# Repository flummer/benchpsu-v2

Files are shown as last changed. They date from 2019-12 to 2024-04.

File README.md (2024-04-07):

# Benchtop PSU v2

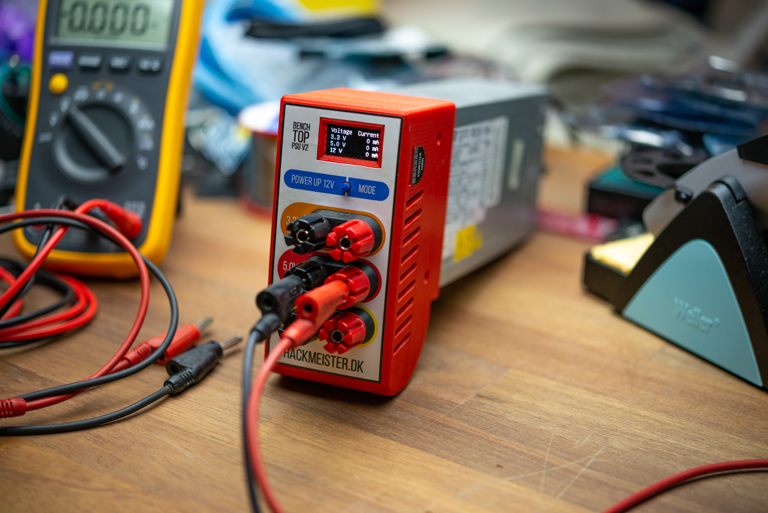
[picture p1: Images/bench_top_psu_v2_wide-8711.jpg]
Benchtop PSU v2


This is a conversion of an HP DPS-800GB server power supply, into a benchtop supply with connectors more commonly used for electronics and electrical prototyping.

It's designed to be relatively easy to make, and not least easier to assemble, as there are no dangling wires to solder, and the front part can be assembled by itself and then mounted on the PSU. The only modification I have done to the PSU is to remove the retaining clip, simply by opening the case and drilling out the rivet, holding it in place. It's not a critical modification, but I prefered to get rid of it.

## Features

This is a fairly simple conversion, and there are 3 fixed outputs:

- 3.3 V (5 A max)
- 5.0 V (2 A max)
- 12 V (30 A max)

The DPS-800GB PSU can deliver **much** more than 30A on 12 V, but the measuring circuit used for that channel has a max rating of 30A and the traces on the PCB probably also have a limit, though they have been made as wide as posssible to cope with a bit more current.

The screen will display the current draw on each output.

As the 3.3 V and 5.0 V outputs are part of the standby system in the DPS-800GB, they are always on, but the 12 V output is controlled via an optocoupler from the microcontroller, and the firmware is set up so that the single button turns that on and off.

## Notes

When mains power is connected, the fan is **not** running, but the PSU will get a bit warm if it sits like that for some time and it will also draw about 15W just sitting there, which isn't ideal. When the 12 V output is enabled, the fan will kick in, but unless you put a heavy load on it, it will only run slowly and not be super noisy, though it isn't silent in any way.

## Electronics

The electronics is build around an ATmega328p microcontroller and 3 ACS712 current sensors with analog output, and the firmware has some magic numbers for converting the value read from the analog inputs into ampere. Those have been found by putting a few known loads on the PSU and looking at the readings. It's a bit hacky, but good enough for a quick measurement if you just need to know if you are in the ballpark.

The banana connectors are the Pomona 6883 Dual Binding post and they are also used to hold the PCB inside the 3D printed case, and the friction of the connector and the 3D print against the case of the DPS-800GB is enough to keep it together, though the 3D model do have holes that match up with the existing screws of the DPS-800GB.

The card edge connector used to match with the DPS-800GB is an Amphenol FCI 10046971-001LF.

## License

The hardware, firmware, 3D models and artwork in this repository are released under the following license:

* the "Creative Commons Attribution-ShareAlike 4.0 International License"
  (CC BY-SA 4.0) full text of this license is included in the LICENSE file
  and a copy can also be found at
  [http://creativecommons.org/licenses/by-sa/4.0/](http://creativecommons.org/licenses/by-sa/4.0/)

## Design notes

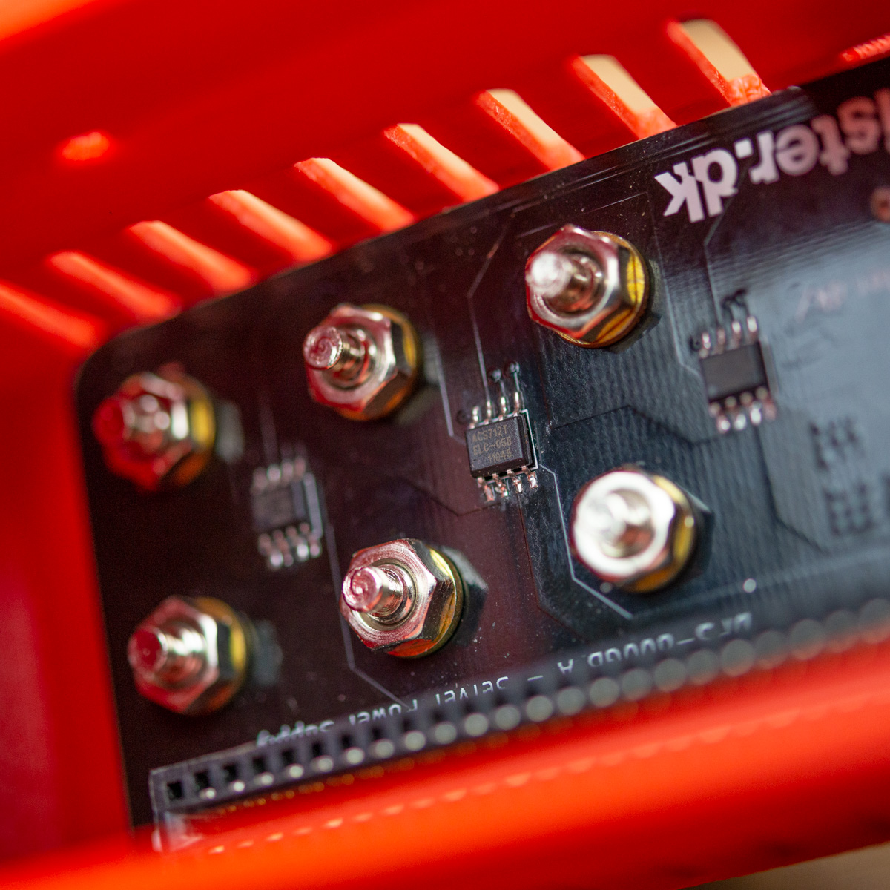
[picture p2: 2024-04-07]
Images/bench_top_psu_v2-8725.jpg

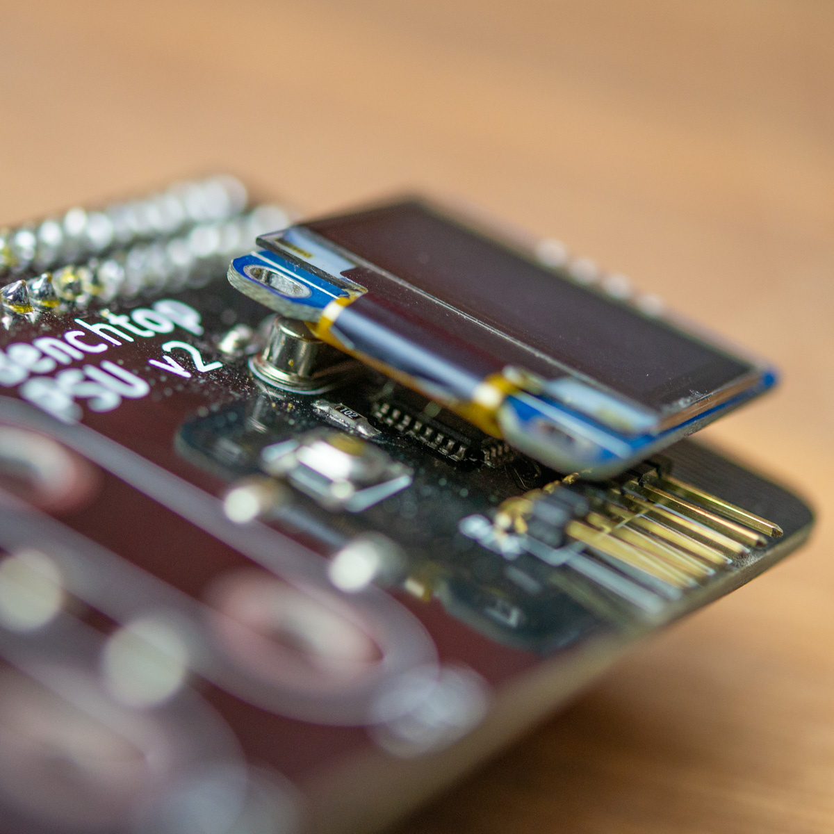
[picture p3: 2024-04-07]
Images/bench_top_psu_v2-8720.jpg

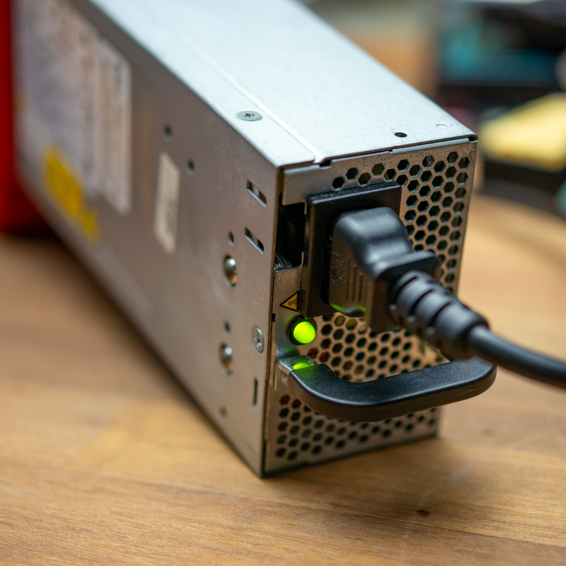
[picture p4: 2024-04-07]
Images/bench_top_psu_v2-8716.jpg

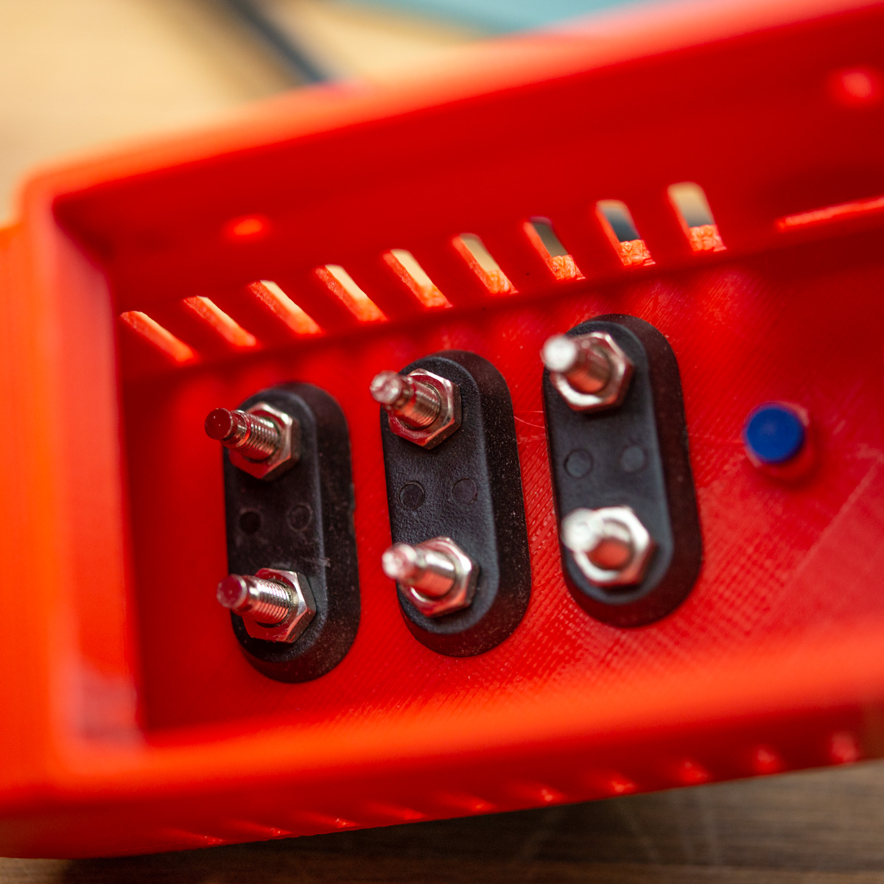
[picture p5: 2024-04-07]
Images/bench_top_psu_v2-8723.jpg

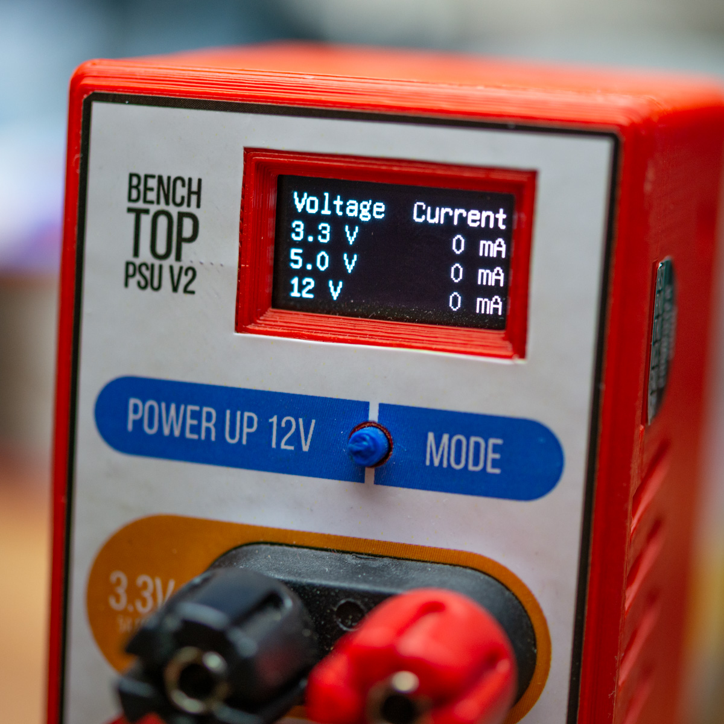
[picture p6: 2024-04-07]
Images/bench_top_psu_v2-8712.jpg

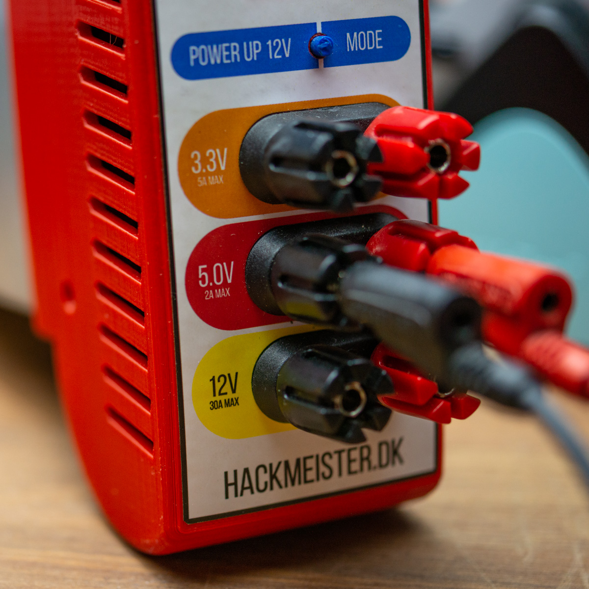
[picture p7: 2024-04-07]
Images/bench_top_psu_v2-8714.jpg

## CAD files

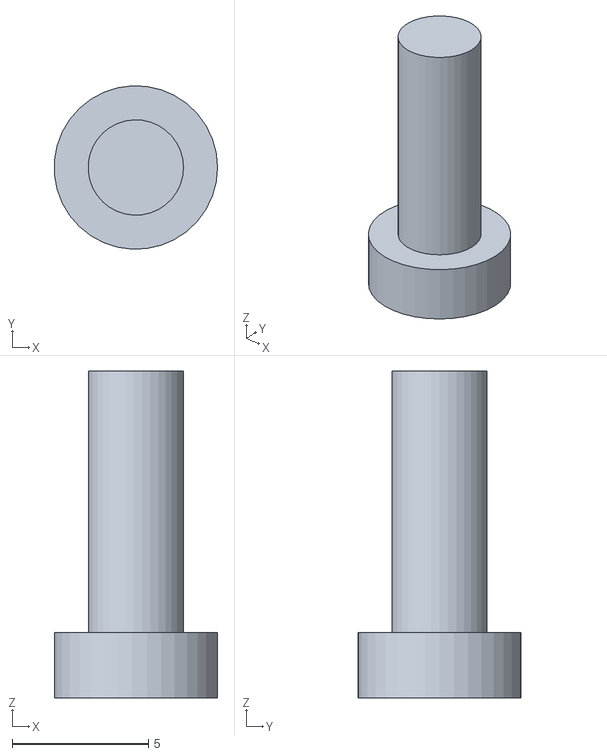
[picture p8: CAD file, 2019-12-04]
Case/button.stl
5.99 x 5.99 x 12.0

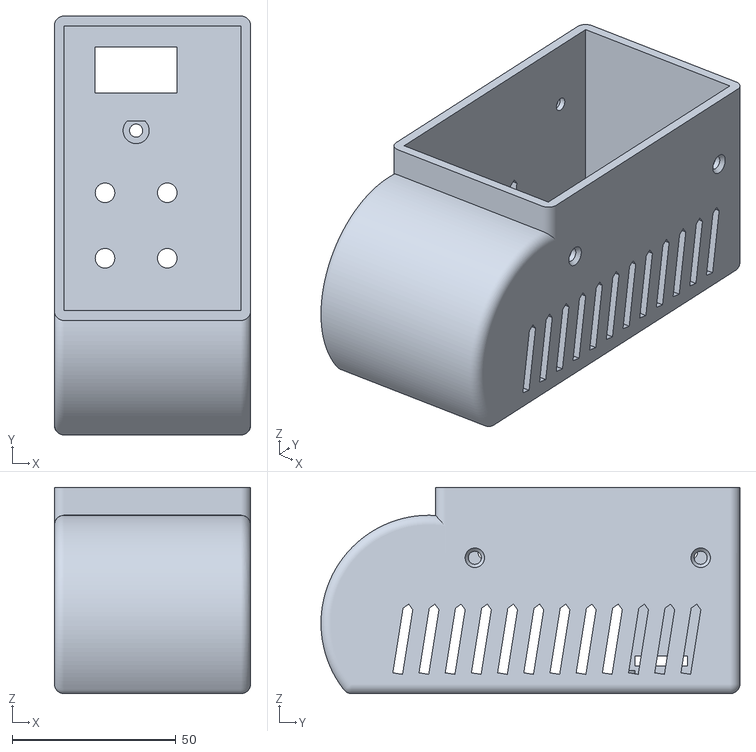
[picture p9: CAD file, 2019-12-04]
Case/benchtop_psu_case.stl
60.0 x 128.0 x 63.0

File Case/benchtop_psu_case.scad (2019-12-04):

/*
 * BenchPSU v2 case to fit DPS800GB A
 * ==================================
 * CC-BY-SA
 *
 * Thomas Flummer, tf@hackmeister.dk
 *
 */


module rounded_edge(radius, length)
{
    difference()
    {
        translate([-(radius+1)/2+1, -(radius+1)/2+1, length/2])
            cube([radius+1, radius+1, length], center = true);
        translate([-radius, -radius, length/2-0.5])
            cylinder(r = radius, h = length+4, center = true, $fn = radius*20);
    }
}

module benchtop_psu_v2_front()
{
    difference()
    {
        union()
        {
            minkowski()
            {
                translate([0, 0, (40+6)/2])
                    cube([54, 104, 40], center = true);
                
                sphere(r = 3, $fn = 60);
            }

            difference()
            {
                translate([0, (104-87)/2, (40+3)+20/2])
                    cube([54+3*2, 87+3*2, 20], center = true);

                translate([54/2+3, (104-87)/2-(87/2+3), 40])
                rotate(-90, [0, 0, 1])
                    rounded_edge(3, 30);

                translate([-(54/2+3), (104-87)/2-(87/2+3), 40])
                rotate(180, [0, 0, 1])
                    rounded_edge(3, 30);

                translate([54/2+3, (104-87)/2+(87/2+3), 40])
                rotate(0, [0, 0, 1])
                    rounded_edge(3, 30);

                translate([-(54/2+3), (104-87)/2+(87/2+3), 40])
                rotate(90, [0, 0, 1])
                    rounded_edge(3, 30);

            }
            
            minkowski()
            {
                difference()
                {
                    translate([0, -(104+3*2)/2+15, (40+3)/2])
                    rotate(90, [0, 1, 0])
                        cylinder(r = (60)/2, h = 54, center = true, $fn = 150);
                    
                    translate([0, -30, -50/2+3])
                        cube([100, 100, 50], center = true);
                }
                
                sphere(r = 3, $fn = 60);
            }
        }
        union()
        {
            difference()
            {
                translate([0, 0, (40+3)/2+3/2])
                    cube([54, 104, 40.1], center = true);
            
                // button support
                difference()
                {
                    translate([54/2-32, 104/2-32, 5/2+2])
                        cylinder(r = 8/2, h = 5, center = true, $fn = 30);
                    
                    translate([54/2-32, 104/2-32+5+3, 5/2+2])
                        cube([10, 10, 6], center = true);
                }
            }

            translate([0, (104-87)/2, (40+3)+20/2])
                cube([54, 87, 20.1], center = true);

            difference()
            {
                translate([0, -(104+3*2)/2+15, (40+3)/2])
                rotate(90, [0, 1, 0])
                    cylinder(r = (60+3)/2-3, h = 54, center = true, $fn = 80);
                
                translate([0, -30, -50/2+3])
                    cube([100, 100, 50], center = true);
            }
    
            // display
            translate([54/2-32, 104/2-13.5, 0])
                cube([25, 14, 10], center = true);

            translate([54/2-32, 104/2-13.5, -2])
            difference()
            {
                cube([25+4, 14+4, 10], center = true);

                translate([0, (14+4)/2, 10/2])
                rotate(45, [1, 0, 0])
                    cube([30, 5, 5], center = true);

                translate([0, -(14+4)/2, 10/2])
                rotate(45, [1, 0, 0])
                    cube([30, 5, 5], center = true);

                translate([(25+4)/2, 0, 10/2])
                rotate(45, [0, 1, 0])
                    cube([5, 30, 5], center = true);

                translate([-(25+4)/2, 0, 10/2])
                rotate(45, [0, 1, 0])
                    cube([5, 30, 5], center = true);
            }
            
            // button
            translate([54/2-32, 104/2-32, 0])
                cylinder(r = 4/2, h = 20, center = true, $fn = 30);

            // 3v3
            translate([54/2-22.5, 104/2-51, 0])
                cylinder(r = 6/2, h = 20, center = true, $fn = 30);

            translate([54/2-41.5, 104/2-51, 0])
                cylinder(r = 6/2, h = 20, center = true, $fn = 30);

            // 5v0
            translate([54/2-22.5, 104/2-71, 0])
                cylinder(r = 6/2, h = 20, center = true, $fn = 30);

            translate([54/2-41.5, 104/2-71, 0])
                cylinder(r = 6/2, h = 20, center = true, $fn = 30);

            // 12v
            translate([54/2-22.5, 104/2-91, 0])
                cylinder(r = 6/2, h = 20, center = true, $fn = 30);

            translate([54/2-41.5, 104/2-91, 0])
                cylinder(r = 6/2, h = 20, center = true, $fn = 30);
            
            // 64 pin connector cutout
            translate([54/2-15/2, 104/2-5/2+1.5, 32/2+3])
                cube([15, 5, 32], center = true);

            translate([54/2-15/2, 104/2-5/2+1.5, 32+3])
            rotate(45, [1, 0, 0])
                cube([15, 5*sqrt(2)/2, 5*sqrt(2)/2], center = true);


            // programming
            translate([-54/2-3/2, 104/2-21, 6+3+1])
                cube([4, 16, 3], center = true);

            // ventilation
            for(i = [3 : 11])
            {
                translate([-54/2-3/2, 40-i*8, 3+3+20/2])
                rotate(-9, [1, 0, 0])
                union()
                {
                        cube([4, 3, 20], center = true);

                    translate([0, 0, 20/2])
                    rotate(45, [1, 0, 0])
                        cube([4, 3*sqrt(2)/2, 3*sqrt(2)/2], center = true);
                }

            }

            for(i = [0 : 11])
            {
                translate([54/2+3/2, 40-i*8, 3+3+20/2])
                rotate(-9, [1, 0, 0])
                union()
                {
                        cube([4, 3, 20], center = true);

                    translate([0, 0, 20/2])
                    rotate(45, [1, 0, 0])
                        cube([4, 3*sqrt(2)/2, 3*sqrt(2)/2], center = true);
                }

            }
            
            // screw holes (right side)
            translate([-54/2-3/2, (104-87)/2+63/2, 40+3])
            rotate(90, [0, 1, 0])
                cylinder(r = 4/2, h = 10, center = true, $fn = 30);

            translate([-54/2-3/2-1.2, (104-87)/2+63/2, 40+3])
            rotate(-90, [0, 1, 0])
                cylinder(r1 = 4/2, r2 = 7/2, h = 2, center = true, $fn = 30);

            translate([-54/2-3/2, (104-87)/2-63/2, 40+3])
            rotate(90, [0, 1, 0])
                cylinder(r = 4/2, h = 10, center = true, $fn = 30);

            translate([-54/2-3/2-1.2, (104-87)/2-63/2, 40+3])
            rotate(-90, [0, 1, 0])
                cylinder(r1 = 4/2, r2 = 7/2, h = 2, center = true, $fn = 30);

            // screw holes (left side)
            translate([54/2+3/2, (104-87)/2+69/2, 40+3-1.5])
            rotate(90, [0, 1, 0])
                cylinder(r = 4/2, h = 10, center = true, $fn = 30);

            translate([54/2+3/2+1.2, (104-87)/2+69/2, 40+3-1.5])
            rotate(90, [0, 1, 0])
                cylinder(r1 = 4/2, r2 = 7/2, h = 2, center = true, $fn = 30);

            translate([54/2+3/2, (104-87)/2-69/2, 40+3-1.5])
            rotate(90, [0, 1, 0])
                cylinder(r = 4/2, h = 10, center = true, $fn = 30);

            translate([54/2+3/2+1.2, (104-87)/2-69/2, 40+3-1.5])
            rotate(90, [0, 1, 0])
                cylinder(r1 = 4/2, r2 = 7/2, h = 2, center = true, $fn = 30);
        }
    }
}

module button()
{
    union()
    {
        translate([0, 0, 12/2])
            cylinder(r = 3.5/2, h = 12, center = true, $fn = 35);

        translate([0, 0, 2.4/2])
            cylinder(r = 6/2, h = 2.4, center = true, $fn = 35);

    }
}

module psu()
{
    color([0.9, 0.9, 0.9])
        cube([54, 87, 215], center = true);
}

    benchtop_psu_v2_front();
    
//    button();


// mockup
/*
rotate(99, [1, 0, 0])
    color([1, 0, 0])
    benchtop_psu_v2_front();

rotate(99, [1, 0, 0])
    translate([54/2-32, 104/2-32, 10.3])
    rotate(180, [1, 0, 0])
    color([0, 0, 0])
    button();


rotate(99, [1, 0, 0])
translate([0, (104-87)/2, 215/2+32+3])
    psu();
*/

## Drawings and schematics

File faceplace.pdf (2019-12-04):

## POWER up 12V MODE

### Bench

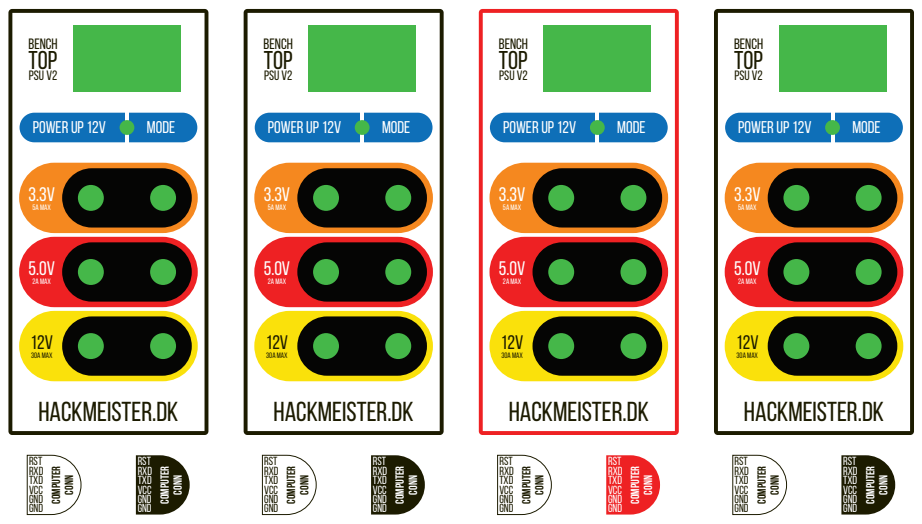
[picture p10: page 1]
GND; VCC; TXD; RXD; RST; 5A max; 2A max; 30A max; HACKMEISTER.DK; TOP; PSU v2; COMPUTER; CONN; Bench TOP; POWER up 12V; MODE

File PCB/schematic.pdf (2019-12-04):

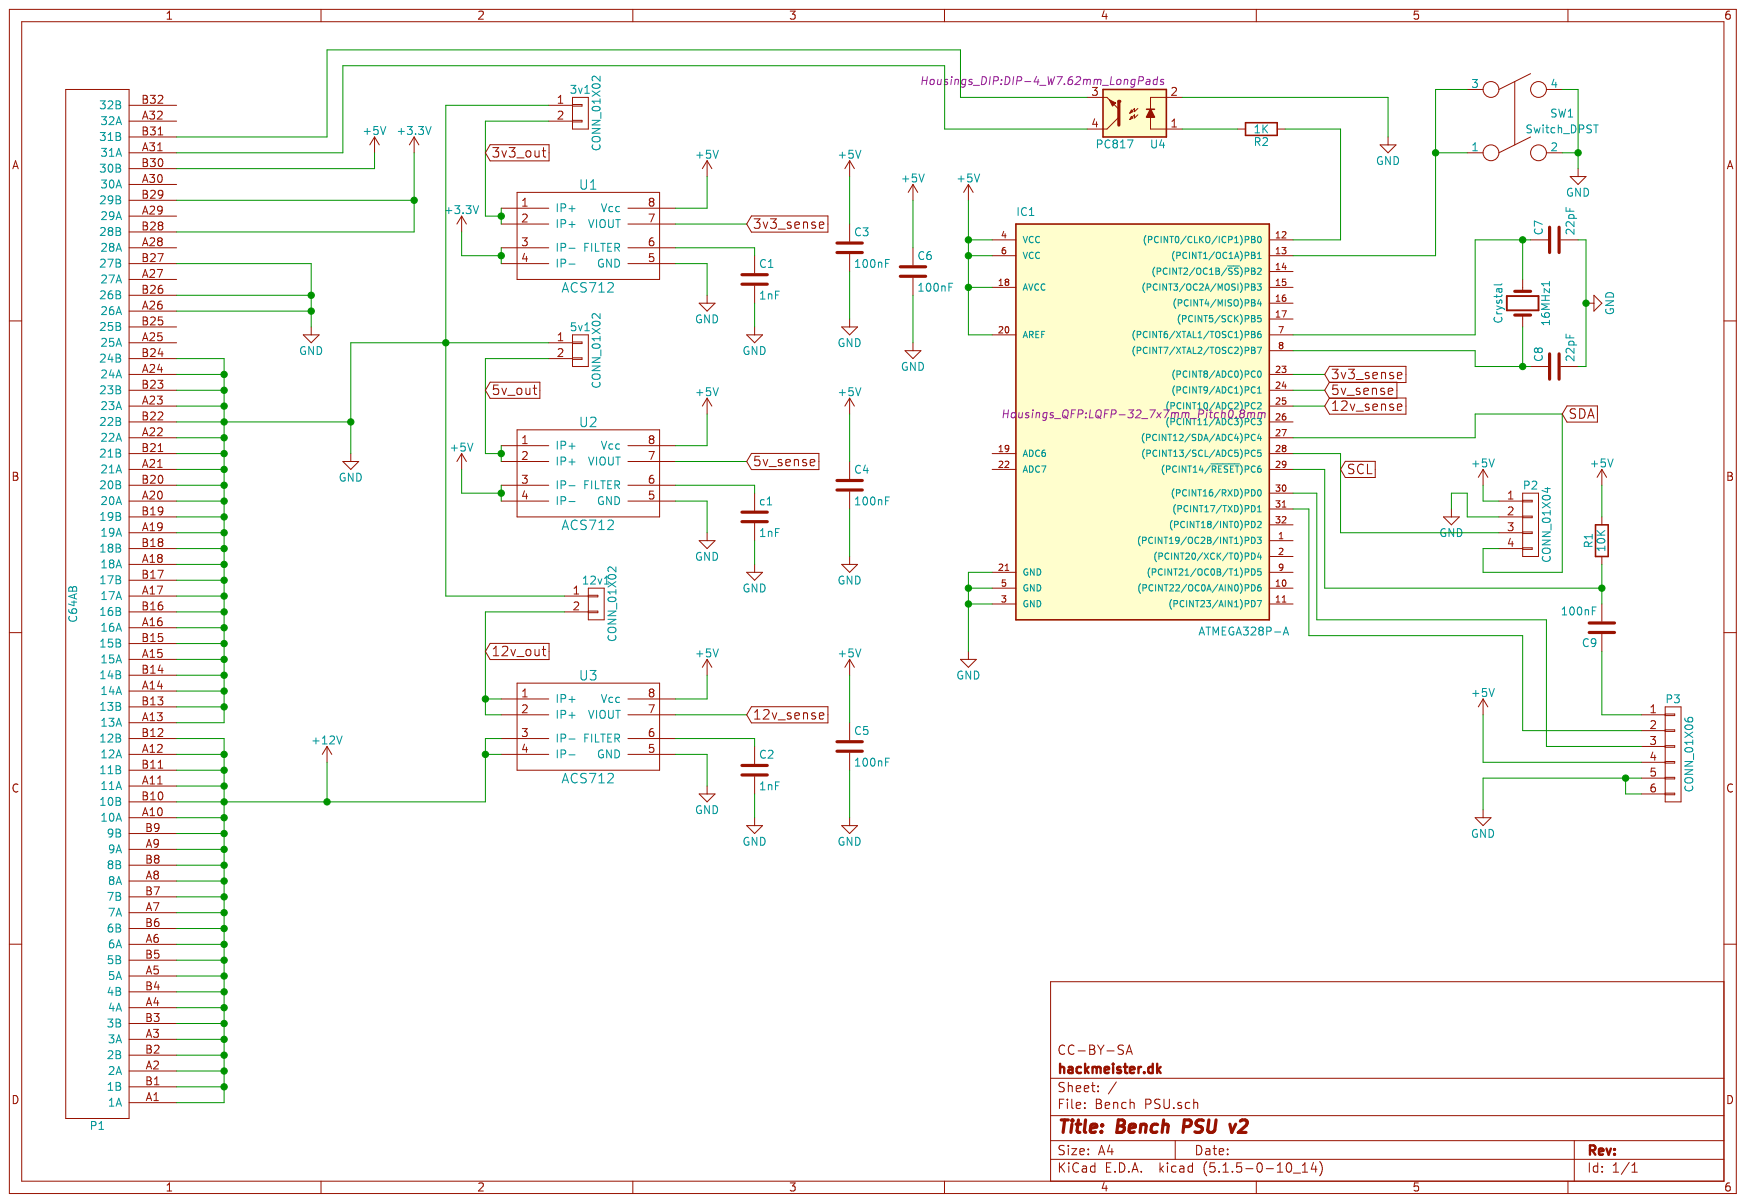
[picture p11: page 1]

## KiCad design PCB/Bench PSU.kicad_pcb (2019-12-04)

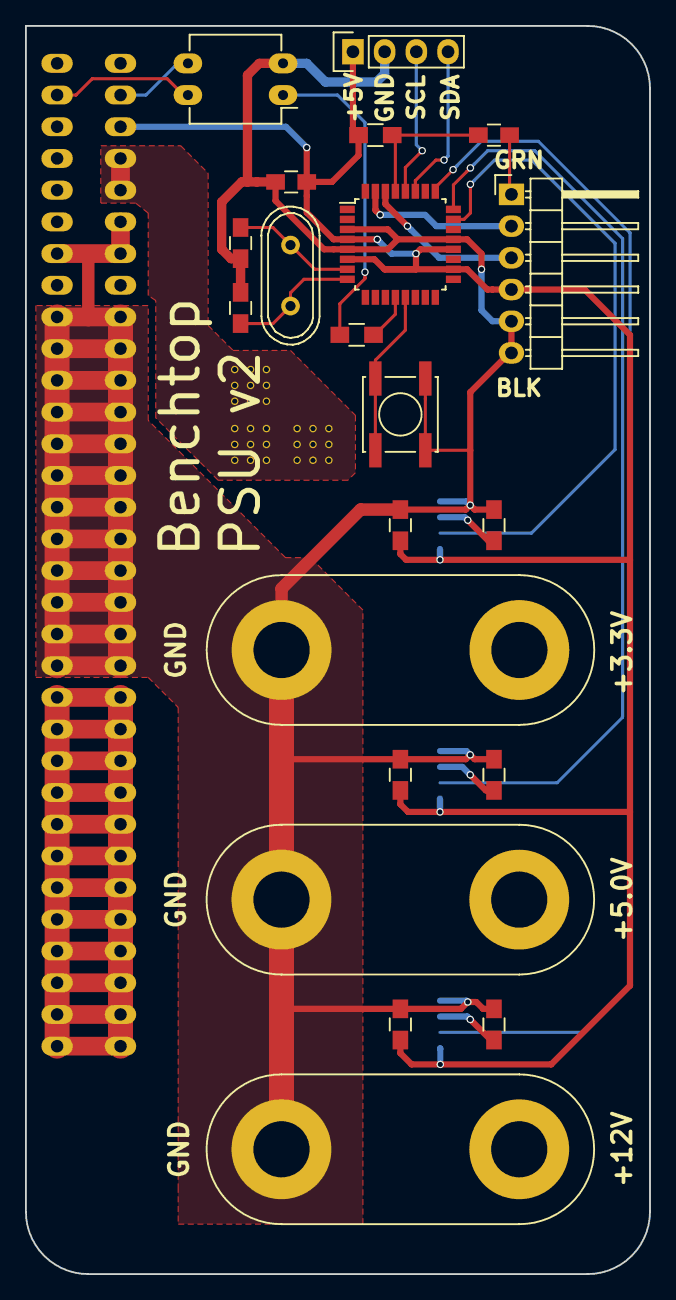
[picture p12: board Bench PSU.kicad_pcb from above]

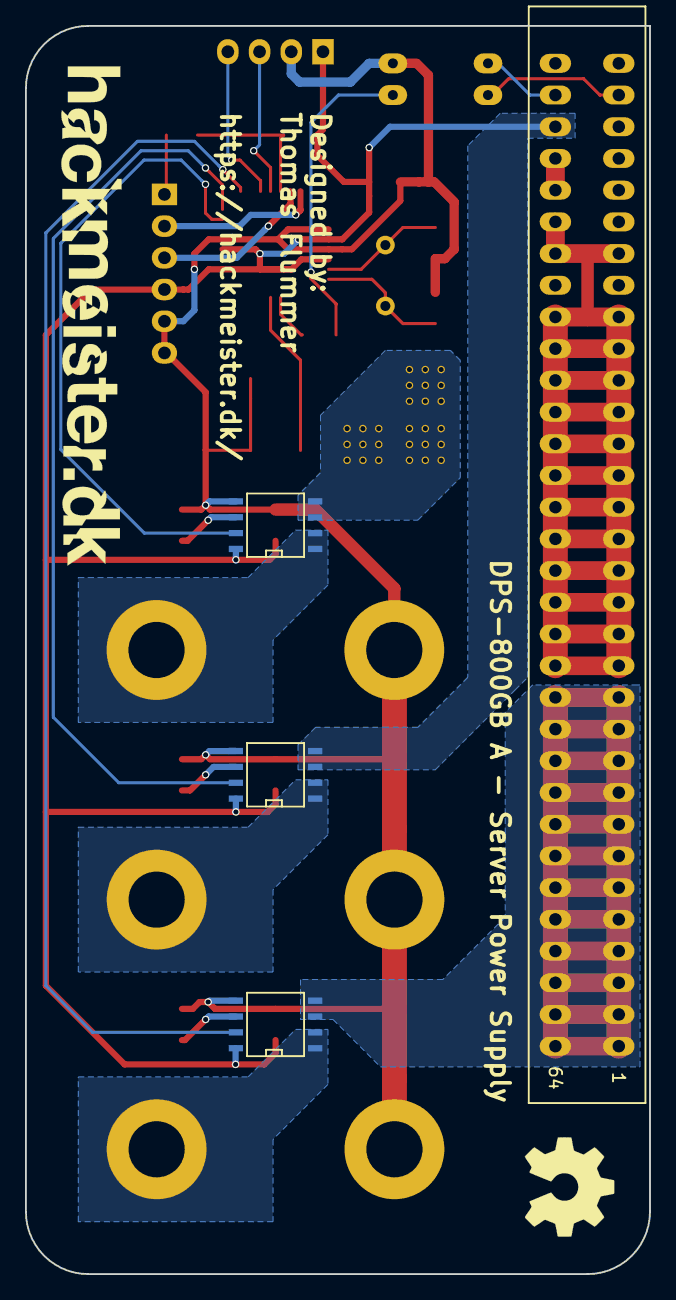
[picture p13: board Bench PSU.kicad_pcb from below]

Board: 2 copper layers, 50.0 x 100.0 mm, 25 parts (4 on the bottom side), 26 nets.

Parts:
3v1, 5v1, 12v1: CONN_01X02; DualBindingPost
16MHz1: Crystal; Crystal_HC49-U_Vertical
C1, C2: 1nF; C_0805_HandSoldering
C3, C4, C5, C6, C9: 100nF; C_0805_HandSoldering
C7, C8: 22pF; C_0805_HandSoldering
IC1: ATMEGA328P-A; LQFP-32_7x7mm_Pitch0.8mm
P1: C64AB; 10046971-001LF
P2: CONN_01X04; Pin_Header_Straight_1x04
P3: CONN_01X06; Pin_Header_Angled_1x06
R1: 10K; R_0805_HandSoldering
R2: R; R_0805_HandSoldering
SW1: Switch_DPST; SW_SPST_EVPBF
U1, U2, U3: ACS712; SOIC-8-N
U4: PC817; DIP-4_W7.62mm_LongPads
c1: 1nF; C_0805_HandSoldering

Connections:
3v3_out: 3v1.2, U1.1, U1.2
3v3_sense: IC1.23, U1.7
5v_out: 5v1.2, U2.1, U2.2
5v_sense: IC1.24, U2.7
12v_out: 12v1.2, U3.1, U3.2
12v_sense: IC1.25, U3.7
+3V3: P1.B28, P1.B29, U1.3, U1.4
+5V: C3.1, C4.1, C5.1, C6.1, IC1.4, IC1.6, IC1.18, IC1.20, P1.B30, P2.1, P3.4, R1.2, U1.8, U2.3, U2.4, U2.8, U3.8
+12V: P1.A1, P1.A2, P1.A3, P1.A4, P1.A5, P1.A6, P1.A7, P1.A8, P1.A9, P1.A10, P1.A11, P1.A12, P1.B1, P1.B2, P1.B3, P1.B4, P1.B5, P1.B6, P1.B7, P1.B8, P1.B9, P1.B10, P1.B11, P1.B12, U3.3, U3.4
GND: 3v1.1, 5v1.1, 12v1.1, C1.2, C2.2, C3.2, C4.2, C5.2, C6.2, C7.2, C8.2, IC1.3, IC1.5, IC1.21, P1.A13, P1.A14, P1.A15, P1.A16, P1.A17, P1.A18, P1.A19, P1.A20, P1.A21, P1.A22, P1.A23, P1.A24, P1.A26, P1.B13, P1.B14, P1.B15, P1.B16, P1.B17, P1.B18, P1.B19, P1.B20, P1.B21, P1.B22, P1.B23, P1.B24, P1.B26, P1.B27, P2.2, P3.5, P3.6, SW1.2, U1.5, U2.5, U3.5, U4.2, c1.2
unnamed: 16MHz1.1, C7.1, IC1.7
unnamed: 16MHz1.2, C8.1, IC1.8
unnamed: C1.1, U1.6
unnamed: C2.1, U3.6
unnamed: C9.1, P3.1
unnamed: C9.2, IC1.29, R1.1
unnamed: IC1.12, R2.1
unnamed: IC1.13, SW1.1
unnamed: IC1.30, P3.3
unnamed: IC1.31, P3.2
unnamed: P1.A31, U4.4
unnamed: P1.B31, U4.3
unnamed: R2.2, U4.1
unnamed: U2.6, c1.1
SCL: IC1.28, P2.3
SDA: IC1.27, P2.4

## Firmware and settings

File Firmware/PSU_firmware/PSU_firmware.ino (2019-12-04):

/******************************************************
 * DPS-800GB Bench PSU controller Firmware
 * 
 * Designed by: Thomas Flummer <tf@hackmeister.dk>
 * 
 * License: CC-BY-SA
 * 
 ******************************************************/

#include <U8glib.h>

U8GLIB_SSD1306_128X64 u8g(U8G_I2C_OPT_NO_ACK);  

const int buttonPin = 9;
const int powerPin = 8;

const int sense3v3Pin = 0;
const int sense5v0Pin = 1;
const int sense12vPin = 2;

int sense3v3Value = 0;
int sense5v0Value = 0;
int sense12vValue = 0;

int powerState = 0;
int buttonState = 0;

void draw() {
  //
  int usage3v3 = (512 - sense3v3Value) * 80;
  if(usage3v3 < 0)
  {
    usage3v3 = 0;
  }

  int usage5v0 = (510 - sense5v0Value) * 28;
  if(usage5v0 < 0)
  {
    usage5v0 = 0;
  }

  int usage12v = (509 - sense12vValue) * 76;
  if(usage12v < 0)
  {
    usage12v = 0;
  }

  char buf [6];

  u8g.setFont(u8g_font_unifont);
  u8g.drawStr( 0, 15, "Voltage  Current");
  u8g.drawStr( 0, 31, "3.3 V         mA");
  sprintf (buf, "%4i", usage3v3);
  u8g.drawStr( 72, 31, buf);
  u8g.drawStr( 0, 47, "5.0 V         mA");
  sprintf (buf, "%4i", usage5v0);
  u8g.drawStr( 72, 47, buf);
  u8g.drawStr( 0, 63, "12 V          mA");

  if(powerState == 0)
  {
    u8g.drawStr( 40, 63, "[off]  -");  
  }
  else
  {
    sprintf (buf, "%5i", usage12v);
    u8g.drawStr( 64, 63, buf);
  }
  //u8g.drawBox(0,0,128,64);

/*
  u8g.setFont(u8g_font_osb26);
  u8g.drawStr(0, 30, "2.45 A");
*/
}

void setup()
{
  // Button setup as input with pull up
  pinMode(buttonPin, INPUT_PULLUP);

  // power pin setup as output
  pinMode(powerPin, OUTPUT);
  digitalWrite(powerPin, LOW);
}

void loop()
{
  // toggle PSU power if button is pressed
  buttonState = digitalRead(buttonPin);
  if(buttonState == LOW && powerState == 0)
  {
    powerState = 1;
  }
  else if(buttonState == LOW && powerState == 1)
  {
    powerState = 0;
  }

  if(powerState == 1)
  {
    digitalWrite(powerPin, HIGH);    
  }
  else
  {
    digitalWrite(powerPin, LOW);
  }

  // read power usage for all 3 outputs
  sense3v3Value = analogRead(sense3v3Pin);
  sense5v0Value = analogRead(sense5v0Pin);
  sense12vValue = analogRead(sense12vPin);

  u8g.firstPage();  
  do {
    draw();
  }
  while( u8g.nextPage() );

  delay(250);
}
